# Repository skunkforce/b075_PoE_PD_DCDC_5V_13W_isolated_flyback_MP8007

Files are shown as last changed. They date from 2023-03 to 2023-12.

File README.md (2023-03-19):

# edgy_board number b075
This design is part of the [edgy board project](https://github.com/skunkforce/edgy_boards). 

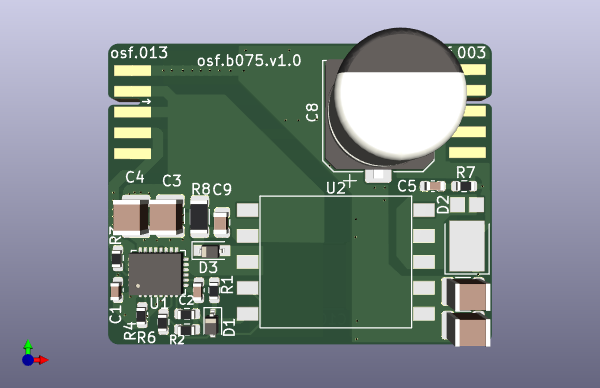
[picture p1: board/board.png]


# getting started
This repository uses submodules. After cloning use the command 

```$ git submodule update --init --recursive```

to pull the submodules before opening the project with kicad. 

# Tests
Tests can be found in [TESTS.md](TESTS.md)

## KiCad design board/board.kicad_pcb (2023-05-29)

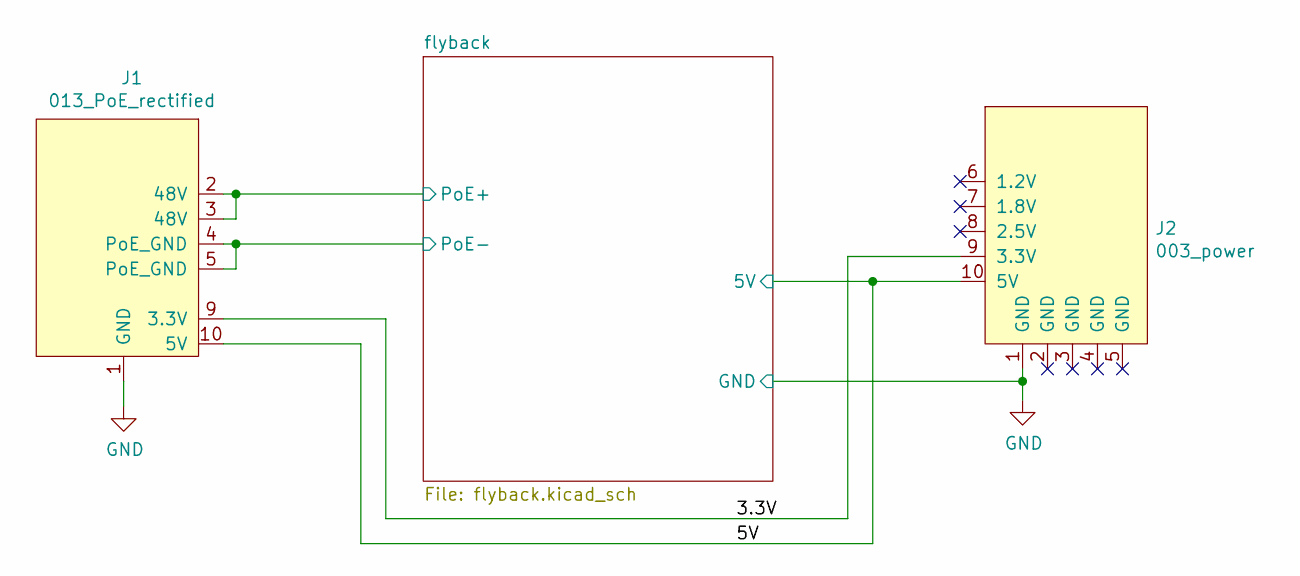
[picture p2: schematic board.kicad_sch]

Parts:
J1: 013_PoE_rectified; on_edge_2x05_device
J2: 003_power; on_edge_2x05_host

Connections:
/3.3V: J1.9 (3.3V), J2.9 (3.3V)
/5V: J1.10 (5V), J2.10 (5V); also elsewhere on the board
/flyback/PoE+: J1.2 (48V), J1.3 (48V); also elsewhere on the board
/flyback/PoE-: J1.4 (PoE_GND), J1.5 (PoE_GND); also elsewhere on the board
GND: J1.1 (GND), J2.1 (GND); also elsewhere on the board

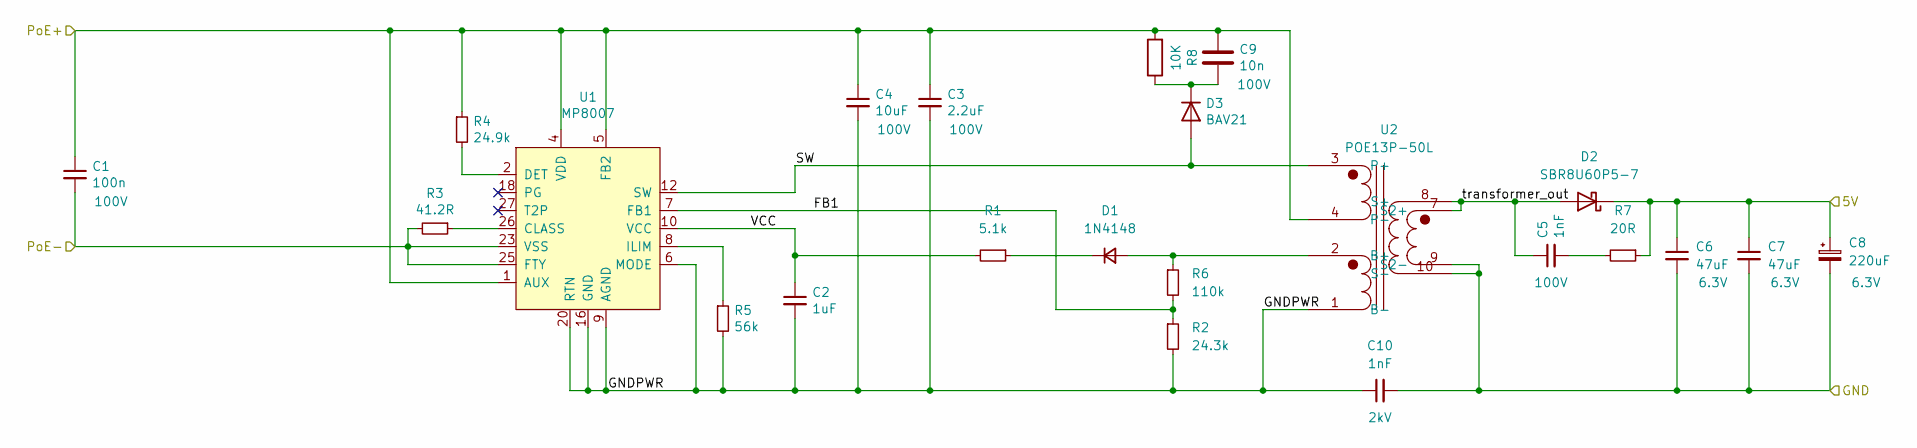
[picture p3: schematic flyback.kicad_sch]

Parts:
C1: 100n; C_0603_1608Metric; Voltage 100V
C2: 1uF; C_0603_1608Metric
C3: 2.2uF; C_1210_3225Metric; Voltage 100V
C4: 10uF; C_1210_3225Metric; Voltage 100V
C5: 1nF; C_0603_1608Metric; Voltage 100V; MPN GRM188R72A102KA01D
C6, C7: 47uF; C_1210_3225Metric; Voltage 6.3V
C8: 220uF; CP_Elec_10x10.5; Voltage 6.3V
C9: 10n; C_0805_2012Metric; Voltage 100V; MPN GRM216R72A103KA01D
C10: 1nF; C_1825_4564Metric; Voltage 2kV
D1: 1N4148; D_SOD-323; DigiKey_PN 1N4148WS_R1_00001
D2: SBR8U60P5-7; D_PowerDI-5
D3: BAV21; D_SOD-323_HandSoldering; DigiKey_PN BAV21WS_R1_00001
R1: 5.1k; R_0603_1608Metric
R2: 24.3k; R_0603_1608Metric
R3: 41.2R; R_0603_1608Metric
R4: 24.9k; R_0603_1608Metric
R5: 56k; R_0603_1608Metric
R6: 110k; R_0603_1608Metric
R7: 20R; R_0603_1608Metric
R8: 10K; R_1206_3216Metric
U1: MP8007; QFN-28-1EP_4x5mm_P0.5mm_EP2.65x3.65mm_ThermalVias
U2: POE13P-50L; Transformer_Coilcraft_POE13P

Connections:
/5V: C6.1, C7.1, C8.1, D2.1 (K), R7.1; also elsewhere on the board
/flyback/FB1: R2.1, R6.2, U1.7 (FB1)
/flyback/GNDPWR: C2.2, C3.2, C4.2, C10.1, R2.2, R5.2, U1.6 (MODE), U1.9 (AGND), U1.14 (NC), U1.15 (NC), U1.16 (GND), U1.17, U1.19 (NC), U1.20 (RTN), U1.21, U1.22 (NC), U1.29 (GND), U2.1 (B-)
/flyback/PoE+: C1.1, C3.1, C4.1, C9.1, R4.1, R8.2, U1.1 (AUX), U1.4 (VDD), U1.5 (FB2), U2.4 (P-); also elsewhere on the board
/flyback/PoE-: C1.2, R3.2, U1.23 (VSS), U1.24, U1.25 (FTY); also elsewhere on the board
/flyback/SW: D3.2 (A), U1.12 (SW), U1.13, U2.3 (P+)
/flyback/VCC: C2.1, R1.2, U1.10 (VCC)
/flyback/transformer_out: C5.1, D2.2 (A), U2.7 (S2+), U2.8 (S+)
GND: C6.2, C7.2, C8.2, C10.2, U2.9 (S2-), U2.10 (S-); also elsewhere on the board
unnamed: C5.2, R7.2
unnamed: C9.2, D3.1 (K), R8.1
unnamed: D1.1 (K), R1.1
unnamed: D1.2 (A), R6.1, U2.2 (B+)
unnamed: R3.1, U1.26 (CLASS)
unnamed: R4.2, U1.2 (DET)
unnamed: R5.1, U1.8 (ILIM)

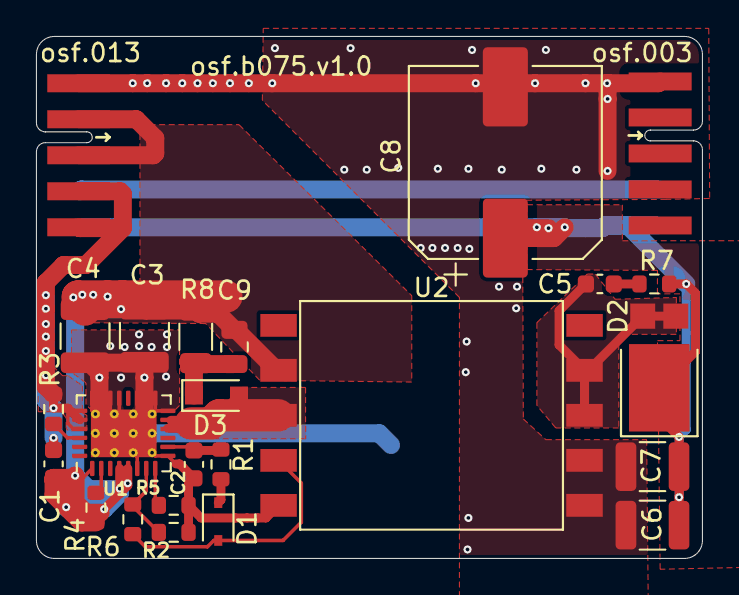
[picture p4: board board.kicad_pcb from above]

Board: 2 copper layers, 37.0 x 29.0 mm, 25 parts (1 on the bottom side), 17 nets.

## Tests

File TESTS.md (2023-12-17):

# initialization test
## setup
Connected 
```mermaid
flowchart LR
  b004 --> b075 
  b075 --> r[100R between pinns 1 and 10 of J2]
  
```
## results
initialization works on a standard PoE switch.

# current test
## setup
Connected
```mermaid
flowchart LR
  b004 --> b075 
  b075 --> r[variable resistor between pinns 1 and 10 of J2]
  
```
## results
| current | voltage |
|--|--|
|1A|5V|
|2A|4.9V|
|2.6A|4.9V|
